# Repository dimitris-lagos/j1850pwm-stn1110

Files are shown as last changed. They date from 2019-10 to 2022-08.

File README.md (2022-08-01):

# j1850pwm-stn1110
OBD 2 interface with atmega328 and STN1110. Output on 16x2 LCD Screen. Implements j1850 pwm protocol.
ATMega328P fuses:
L: 0xFF
H: 0xDD
E: 0xF8
LB: 0xFD

Cad 3D Model Schematic

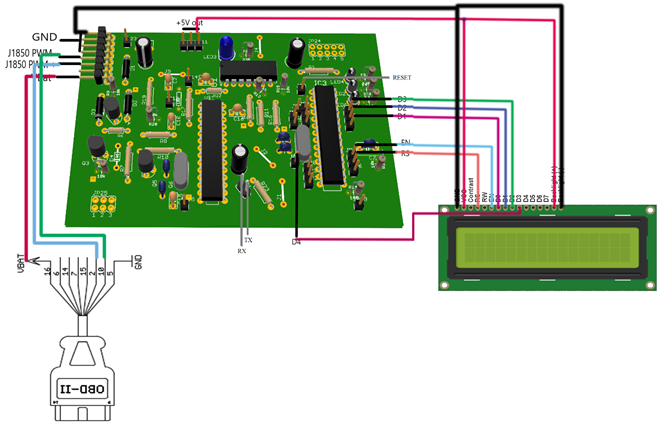
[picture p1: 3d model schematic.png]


Prototype connected to ECU Emulator

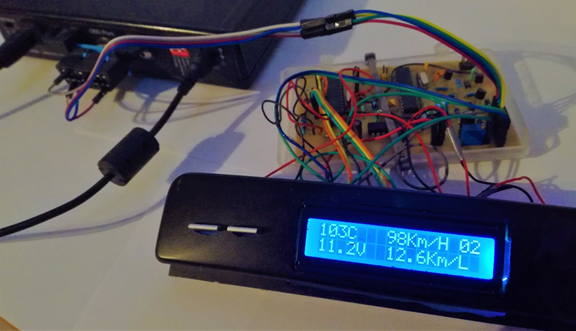
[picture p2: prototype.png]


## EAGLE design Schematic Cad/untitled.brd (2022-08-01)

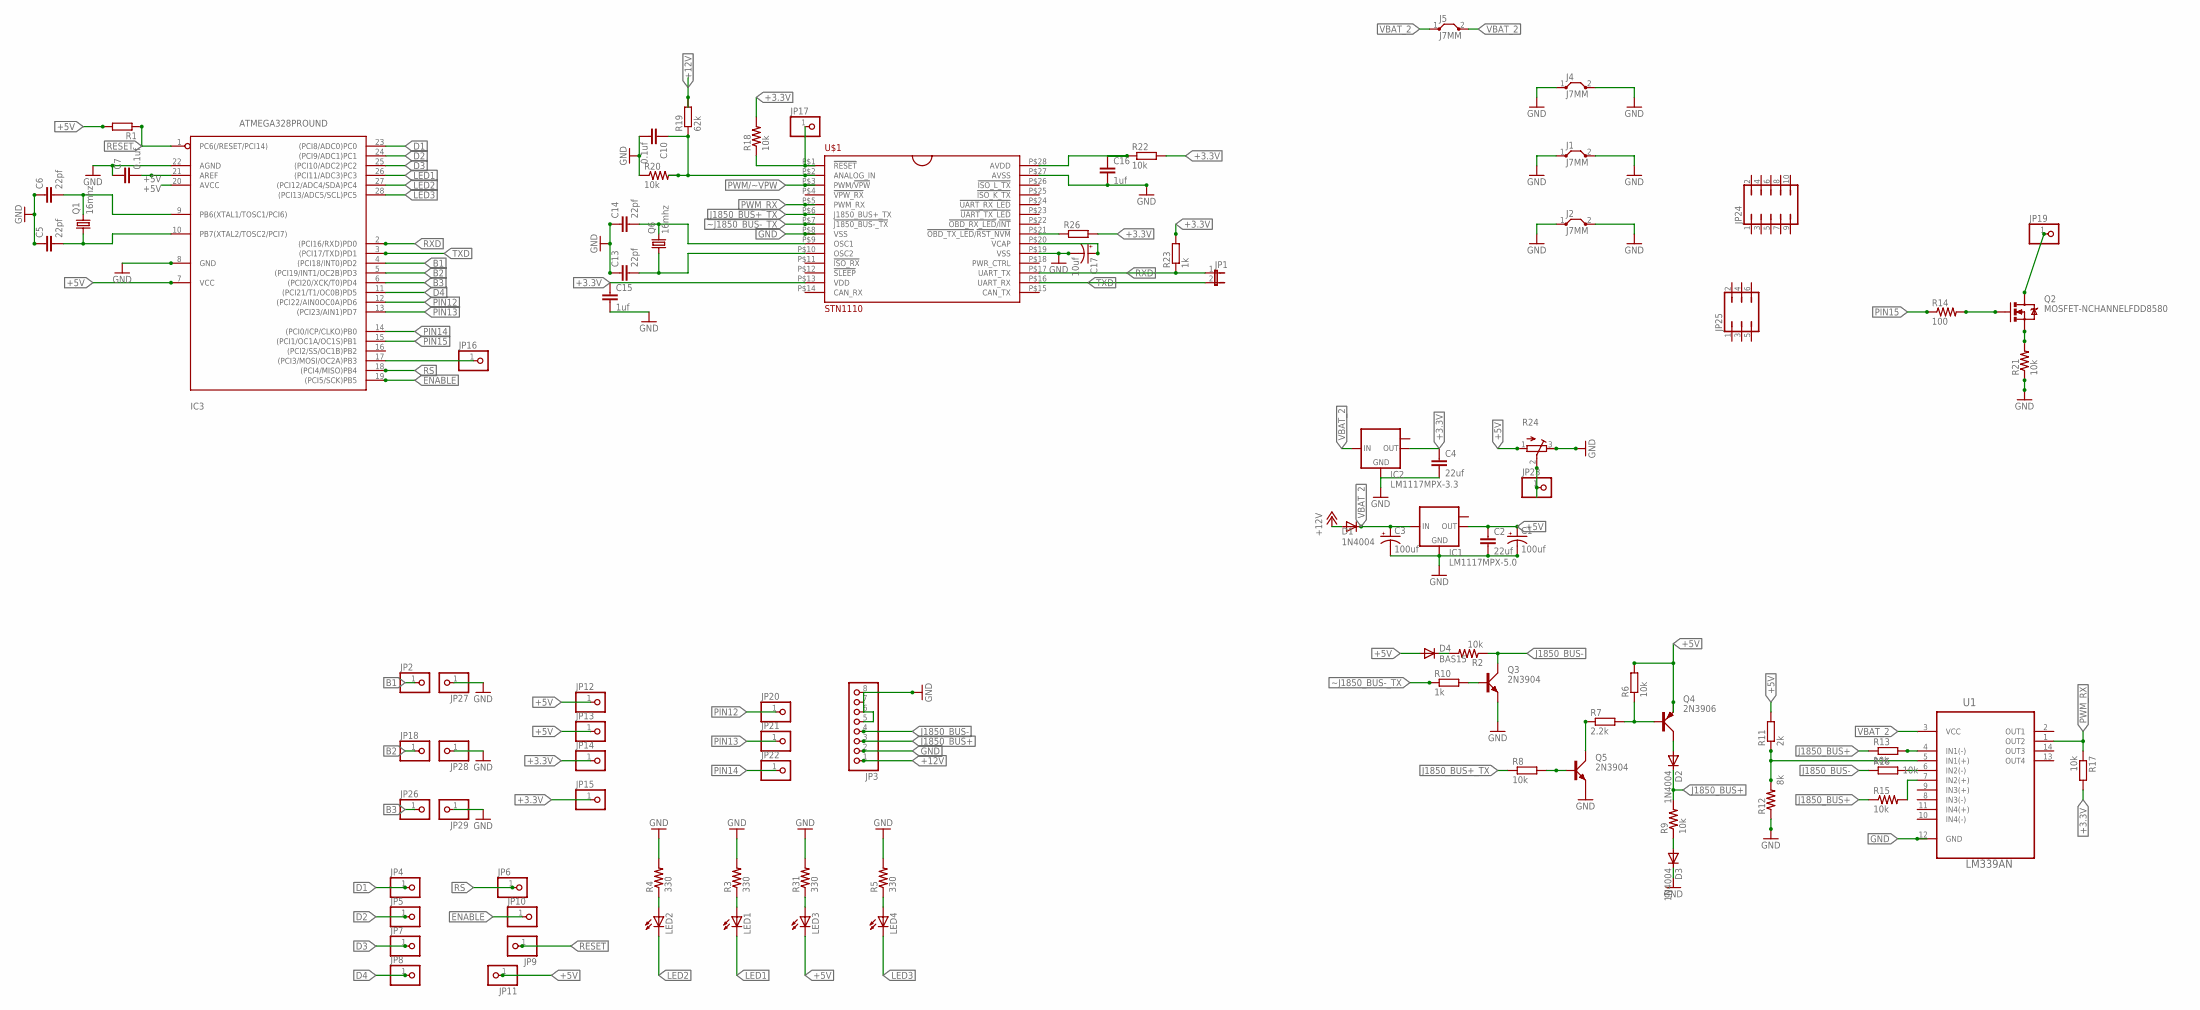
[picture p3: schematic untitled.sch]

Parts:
C1, C3: 100uf; CPOL-RADIAL-10UF-25V-KIT
C2, C4: 22uf; C025-025X050
C5, C6, C13, C14: 22pf; CAP-PTH-SMALL
C7: 0.1uf; C5B4.5
C10: 0.1uf; C025-025X050
C15, C16: 1uf; C025-025X050
C17: 10uf; CPOL-RADIAL-10UF-25V
D1, D2, D3: 1N4004; DO41-10
D4: BAS15; DO34-7
IC1: LM1117MPX-5.0; SOT223
IC2: LM1117MPX-3.3; SOT223
IC3: ATMEGA328PROUND; DIL28-3-ROUND
J1, J2, J4, J5: J7MM; 07
JP1: JP1E; JP1
JP2, JP4, JP5, JP6, JP7, JP8, JP9, JP10, JP11, JP12, JP13, JP14, JP15, JP16, JP17, JP18, JP19, JP20, JP21, JP22, JP23, JP26, JP27, JP28, JP29: PINHD-1X1; 1X01
JP3: PINHD-1X8; 1X08
JP24: JP5Q
JP25: JP3Q
LED1, LED2, LED4: LED3MM
LED3: LED5MM
Q1, Q6: 16mhz; HC49/S
Q2: MOSFET-NCHANNELFDD8580; DPAK
Q3, Q5: 2N3904; TO92D
Q4: 2N3906; TO92D
R1: R-EU_0207/12; 0207/12
R2, R9, R15, R20, R21: 10k; AXIAL-0.1EZ
R3, R4, R5, R31: 330; AXIAL-0.1EZ
R6, R22: 10k; 0204/7
R7: 2.2k; 0207/12
R8, R13, R16: 10k; 0207/10
R10: 1k; 0207/12
R11: 2k; 0207/10
R12: 8k; AXIAL-0.1EZ
R14: 100; AXIAL-0.1EZ
R17: 10k; 0207/12
R18: 10k; AXIAL-0.3EZ
R19: 62k; 0207/12
R23: 1k; 0207/10
R24: R-TRIMM74W; RTRIM74W
R26: R-EU_M3516; M3516
U1: LM339AN; DIP254P762X508-14
U$1: STN1110; SPDIP28

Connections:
+3.3V: C4.1, C15.1, IC2.2 (OUT), JP14.1, JP15.1, R17.2, R18.P$2 (2), R22.2, R23.2, R26.2, U$1.P$13 (VDD)
+5V: C1.1 (+), C2.1, C7.2, D4.A, IC1.2 (OUT), IC3.7 (VCC), IC3.20 (AVCC), IC3.21 (AREF), JP11.1, JP12.1, JP13.1, LED3.K (C), Q4.E, R1.2, R6.2, R11.2, R24.1 (E)
+12V: D1.A, JP3.1, R19.2
AAA: C10.1, R19.1, R20.P$2 (2), U$1.P$2 (ANALOG_IN)
B1: IC3.4 ((PCI18/INT0)PD2), JP2.1
B2: IC3.5 ((PCI19/INT1/OC2B)PD3), JP18.1
B3: IC3.6 ((PCI20/XCK/T0)PD4), JP26.1
D1: IC3.23 ((PCI8/ADC0)PC0), JP4.1
D2: IC3.24 ((PCI9/ADC1)PC1), JP5.1
D3: IC3.25 ((PCI10/ADC2)PC2), JP7.1
D4: IC3.11 ((PCI21/T1/OC0B)PD5), JP8.1
ENABLE: IC3.19 ((PCI5/SCK)PB5), JP10.1
GND: C1.2 (-), C2.2, C3.2 (-), C4.2, C5.1, C6.1, C7.1, C10.2, C13.1, C14.1, C15.2, C16.2, C17.2 (-), D3.C, IC1.1 (GND), IC2.1 (GND), IC3.8 (GND), IC3.22 (AGND), J1.1, J1.2, J2.1, J2.2, J4.1, J4.2, JP3.2, JP3.5, JP3.6, JP3.7, JP3.8, JP27.1, JP28.1, JP29.1, Q3.E, Q5.E, R3.P$2 (2), R4.P$2 (2), R5.P$2 (2), R12.P$1 (1), R20.P$1 (1), R21.P$1 (1), R24.3 (A), R31.P$2 (2), U1.12 (GND), U$1.P$8 (VSS), U$1.P$19 (VSS), U$1.P$27 (AVSS)
J1850_BUS+: D2.C, JP3.3, R9.P$2 (2), R13.1, R15.P$1 (1)
J1850_BUS+_TX: R8.1, U$1.P$6 (J1850_BUS+_TX)
J1850_BUS-: JP3.4, Q3.C, R2.P$1 (1), R16.1
LED1: IC3.26 ((PCI11/ADC3)PC3), LED1.K (C)
LED2: IC3.27 ((PCI12/ADC4/SDA)PC4), LED2.K (C)
LED3: IC3.28 ((PCI13/ADC5/SCL)PC5), LED4.K (C)
unnamed: R26.1, U$1.P$21 (!OBD_TX_LED!/!RST_NVM!)
unnamed: D4.C, R2.P$2 (2)
unnamed: Q4.B, R6.1, R7.2
unnamed: R13.2, U1.4 (IN1(-))
unnamed: Q5.C, R7.1
unnamed: D2.A, Q4.C
unnamed: Q5.B, R8.2
unnamed: Q3.B, R10.2
unnamed: D3.A, R9.P$1 (1)
unnamed: R15.P$2 (2), U1.7 (IN2(+))
unnamed: C16.1, R22.1, U$1.P$28 (AVDD)
unnamed: R16.2, U1.6 (IN2(-))
unnamed: C6.2, IC3.9 (PB6(XTAL1/TOSC1/PCI6)), Q1.2
unnamed: R11.1, R12.P$2 (2), U1.5 (IN1(+))
unnamed: C5.2, IC3.10 (PB7(XTAL2/TOSC2/PCI7)), Q1.1
unnamed: C17.1 (+), U$1.P$20 (VCAP)
unnamed: C14.2, Q6.2, U$1.P$9 (OSC1)
unnamed: C13.2, Q6.1, U$1.P$10 (OSC2)
unnamed: LED3.A, R31.P$1 (1)
unnamed: LED1.A, R3.P$1 (1)
unnamed: JP17.1, R18.P$1 (1), U$1.P$1 (!RESET!)
unnamed: LED2.A, R4.P$1 (1)
unnamed: LED4.A, R5.P$1 (1)
unnamed: IC3.17 ((PCI3/MOSI/OC2A)PB3), JP16.1
unnamed: Q2.1 (G), R14.P$2 (2)
unnamed: Q2.3 (S), R21.P$2 (2)
unnamed: JP23.1, R24.2 (S)
unnamed: JP19.1, Q2.4 (D)
PIN12: IC3.12 ((PCI22/AIN0OC0A)PD6), JP20.1
PIN13: IC3.13 ((PCI23/AIN1)PD7), JP21.1
PIN14: IC3.14 ((PCI0/ICP/CLKO)PB0), JP22.1
PIN15: IC3.15 ((PCI1/OC1A/OC1S)PB1), R14.P$1 (1)
PWM/~VPW: U$1.P$3 (PWM/!VPW!)
PWM_RX: R17.1, U1.1 (OUT2), U$1.P$5 (PWM_RX)
RESET: IC3.1 (PC6(/RESET/PCI14)), JP9.1, R1.1
RS: IC3.18 ((PCI4/MISO)PB4), JP6.1
RXD: IC3.2 ((PCI16/RXD)PD0), JP1.1, R23.1, U$1.P$17 (UART_TX)
TXD: IC3.3 ((PCI17/TXD)PD1), JP1.2, U$1.P$16 (UART_RX)
VBAT_2: C3.1 (+), D1.C, IC1.3 (IN), IC2.3 (IN), J5.1, J5.2, U1.3 (VCC)
~J1850_BUS-_TX: R10.1, U$1.P$7 (!J1850_BUS-_TX!)

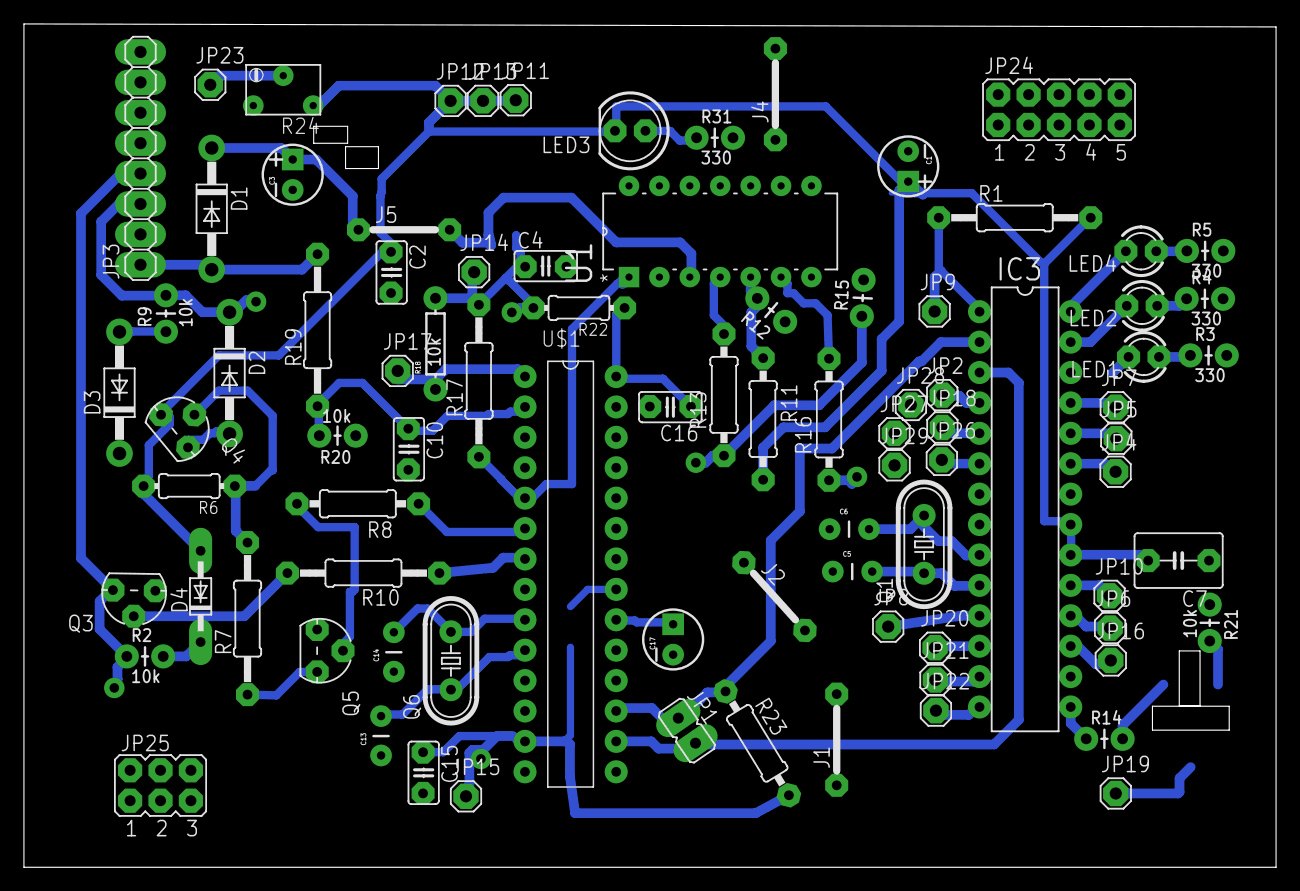
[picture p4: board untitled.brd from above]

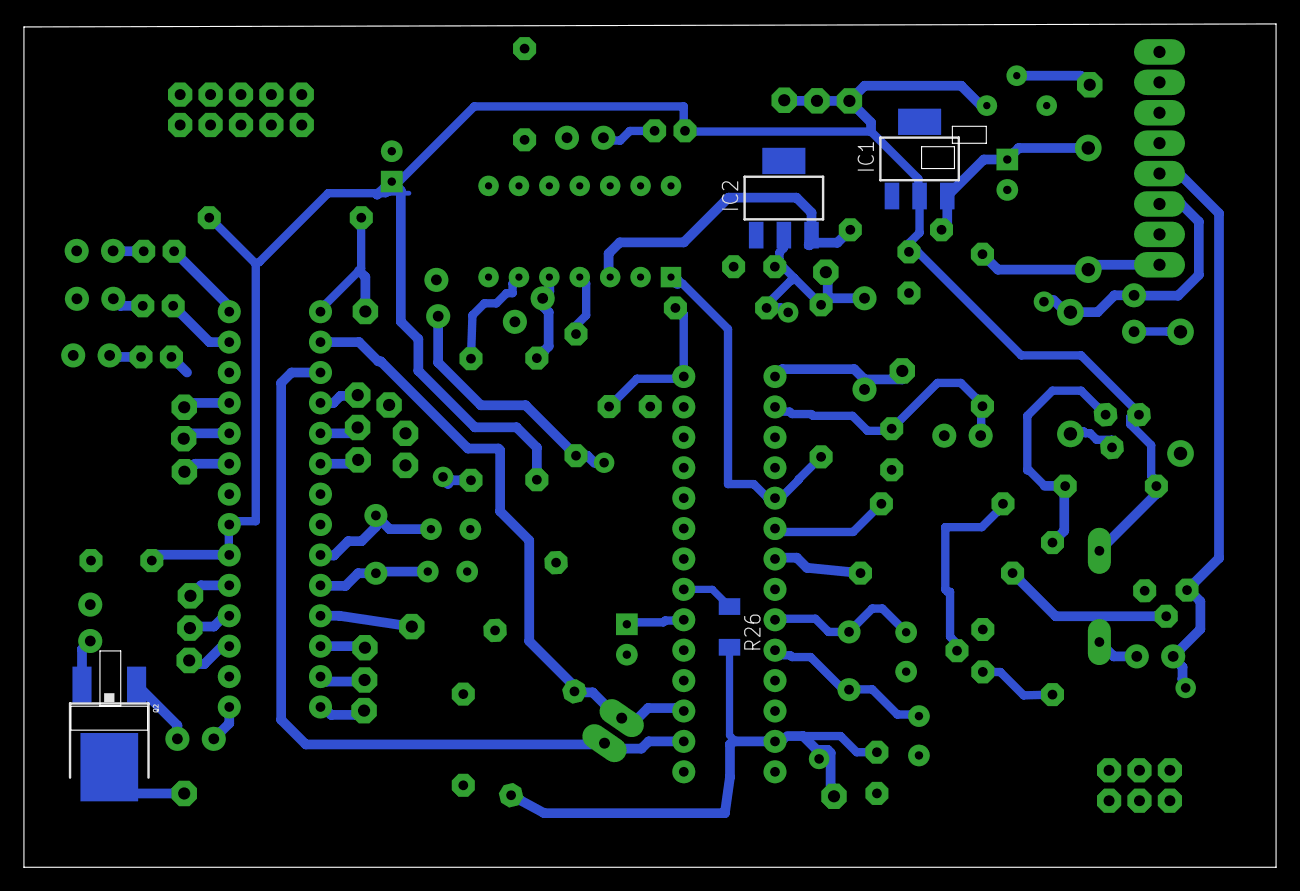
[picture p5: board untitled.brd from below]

Board: 2 copper layers, 104.6 x 70.5 mm, 91 parts (4 on the bottom side), 58 nets.

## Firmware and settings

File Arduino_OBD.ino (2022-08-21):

#include <SoftwareSerial.h> //Χρήση της βιβλιοθήκης που δίνει την δυνατότητα για σειριακή σύνδεση με υλοποίση επιπέδου λογισμικού
#include <avr/wdt.h>        //Χρήση της βιβλιοθήκης υπεύθυνης για την λειτουργία του watchdog timer και συναρτήσεων καθυστέρησης
#include <avr/pgmspace.h>   //Χρήση της EEPROM του ATmega328 για την αποθήκευση των String, ώστε να εξοικονομηθεί χώρος runtime στην sram
#include <LiquidCrystal.h>  // Βιβλιοθήκη που διαχειρίζεται την διασύνδεση με την οθόνη LCD
#include "global.h"
#include "OBD_Interface.h"
#include "LCD_Interface.h"
#include "Debouncy.h"

#define RED_LED 19
#define VENTILATOR_PIN 9
#define BUTTON_1_PIN 2
#define BUTTON_2_PIN 3

/* Η διασύνδεση:
Button Digital Pin 16
LED    Digital Pin 19
Mosfet Digital Pin 9
*/
/* Τμήμα δήλωσης global μεταβλητών */

Debouncy Debouncy_Buttons;
int counter = 0;
float previous_cycle_sterm = 0.00;
float total_cons = 0.00000;// Total consuumption of the vehicle for the current session
float temp_cons = 0.00000;
float real_time_cons = 0.00000;
int menu = 0;
boolean dtc = false;

int threshold = 95;
int temp_thresh = 95;
int analogPin = A3; // potentiometer wiper (middle terminal) connected to analog pin 3
                    // outside leads to ground and +5V

/* Αρχικοποίηση βιβλιοθήκης που διαχειρίζεται την επικοινωνία με την οθόνη,
 με τους ακροδέκτες του Arduino που συνδέονται στην οθόνη  */
LiquidCrystal lcd(12, 13, 5, 14, 15, 16); // LiquidCrystal(rs, enable, d4, d5, d6, d7)

/* Set timer1 interrupt at 1Hz */
void setup_1hz_timer_interrupt(){
  TCCR1A = 0;                                                  // set entire TCCR1A register to 0
  TCCR1B = 0;                                                  // same for TCCR1B
  TCNT1 = 0;                                                   // initialize counter value to 0
  // set compare match register for 1hz increments
  OCR1A = 15624; // = (16*10^6) / (1*1024) - 1 (must be <65536)
  // turn on CTC mode
  TCCR1B |= (1 << WGM12);
  // Set CS12 and CS10 bits for 1024 prescaler
  TCCR1B |= (1 << CS12) | (1 << CS10);
  // enable timer compare interrupt
  TIMSK1 |= (1 << OCIE1A);
}


/* Setup the i/o pin that drives the mosfet that turns on and off the fridge ventilator */
void setup_ventilator_mosfet_driver_pin(){
  pinMode(VENTILATOR_PIN, OUTPUT);   //Ορισμός ακροδέκτη 9 ως έξοδο ventilator mosfet
  digitalWrite(VENTILATOR_PIN, LOW); // ventilator off
}

/* Η συνάρτηση που αρχικοποιεί τις βασικές ρυθμίσεις για την διασύνδεση
 των περιφερειακών και των λειτουργιών του προγράμματος */
void setup()
{
  Debouncy_Buttons.setupDebouncedButton(BUTTON_1_PIN, button1);
  Debouncy_Buttons.setupDebouncedButton(BUTTON_2_PIN, button2);
  setup_ventilator_mosfet_driver_pin();
  init_STN_Serial_Interface();
  // set up the LCD's number of columns and rows:
  lcd.begin(LCD_NUMBER_OF_COLUMNS, LCD_NUMBER_OF_ROWS); //Ορισμός γραμμών και στηλών της οθόνης(2x16)
  pinMode(RED_LED, OUTPUT);                                  //Ορισμός ακροδέκτη 19 ως έξοδο(LED 1)
  setup_1hz_timer_interrupt();

  lcd.clear();
  digitalWrite(RED_LED, HIGH); // LED on
  delay(1000);            // Καθυστέρηση 1sec
  lcd.setCursor(0, 0);    /* μετακίνηση του κέρσορα στην πρώτη γραμμή και πρώτη στήλη της οθόνης */
  lcd.write(WELLCOME_TEXT); /* Γράψε στην οθόνη το κείμενο εισαγωγής*/
  digitalWrite(RED_LED, LOW);  // LED off
  delay(1000);
  wait_for_STN_ready();
  setup_STN_communication_properties();
  menu = 0;
  send_init_page_to_lcd();


  sei();       //ενεργοποίηση της εξυπηρέτησης των διακοπών
}

void send_init_page_to_lcd(){
  lcd.setCursor(0, 1);
  float fuel_lvl = read_fuel_lvl();
  lcd.print(fuel_lvl, 1);
  lcd.print(" %F  ");
  lcd.print(calculate_fuel_in_liters(fuel_lvl), 1);
  lcd.print(" L");
  delay(5000); //περίμενε 5"
}

ISR(TIMER1_COMPA_vect)
{
  if (counter == 0)
  {
    counter = 1;
  }
  total_cons += (temp_cons / (float)counter);
  temp_cons = 0;
  counter = 0;
}



void loop()
{
  read_temp_threshold();
  int coolant_temp = read_coolant_temperature();//Διάβασε την θερμοκρασία του οχήματος
  float fuel_consumption = calculate_fuel_consumption();
  float milage = calculate_milage(fuel_consumption);
  if(dtc){
    dtc = false;
    read_dtc();
  }
  switch (menu)
  {
  case 0: //Επίλεξε σελίδα πληροφοριών 1
    char battery_voltage[6];
    read_battery_voltage(battery_voltage);
    send_page1_to_lcd(coolant_temp, battery_voltage, fuel_consumption, milage);    //Στείλε τα δεδομένα στην οθόνη
    break;
  case 1: //Επίλεξε σελίδα πληροφοριών 2
    send_page2_to_lcd(read_fuel_lvl(), read_fstat());        //Στείλε τα δεδομένα στην οθόνη
    break;
  case 2://Επίλεξε σελίδα πληροφοριών 3
    FordSpecificTemperatures fordTemps;
    read_Ford_specific_temperatures(&fordTemps); //Διάβασε την θερμοκρασία των κυλίνδρων
    send_page3_to_lcd(coolant_temp, fordTemps.uknown_temperature, fordTemps.cylinder_temperature); //Στείλε τα δεδομένα στην οθόνη
    break;
  case 3: //Επίλεξε σελίδα πληροφοριών 3
    send_page4_to_lcd(read_maf(), read_oxvolts(), previous_cycle_sterm, read_fterm());        //Στείλε τα δεδομένα στην οθόνη
    break;
  // case 4:
  //  send_page5_to_lcd(medium_milage);
  //  break;
  }
  delay(10);
}

 /* Συνάρτηση που διαχειρίζεται το πάτημα του κουμπιού 1 */
void button1(unsigned int holdTime){
    ++menu;
    if (menu == 4){
      menu = 0;
    }
    delay(20);
}

/* Συνάρτηση που διαχειρίζεται το πάτημα του κουμπιού 2 */
void button2(unsigned int holdTime) {
    delay(50);
    dtc = true;
} 


void read_temp_threshold()
{
  int val = analogRead(analogPin);
  if (val >= 0 && val < 85)
    threshold = 90;
  else if (val >= 86 && val < 170)
    threshold = 101;
  else if (val >= 171 && val < 255)
    threshold = 102;
  else if (val >= 256 && val < 340)
    threshold = 103;
  else if (val >= 341 && val < 425)
    threshold = 104;
  else if (val >= 426 && val < 510)
    threshold = 105;
  else if (val >= 511 && val < 595)
    threshold = 106;
  else if (val >= 596 && val < 680)
    threshold = 107;
  else if (val >= 681 && val < 765)
    threshold = 108;
  else if (val >= 766 && val < 850)
    threshold = 109;
  else if (val >= 851 && val < 935)
    threshold = 110;
  else if (val >= 936)
    threshold = 120;
  if (threshold != temp_thresh)
  {
    temp_thresh = threshold;
    inform_temperature_threshold_changed();
  }
}

void inform_temperature_threshold_changed()
{
  lcd.clear();
  lcd.setCursor(1, 0);
  lcd.print(threshold, DEC);
  lcd.print("C Threshold");
  delay(200);
}


void check_coolant_temperature_threshold(int temperature)
{
  if (temperature > threshold && temperature < 250)
  {
    digitalWrite(RED_LED, HIGH);
    digitalWrite(VENTILATOR_PIN, HIGH);
  } /* Αν η θερμοκρασία του ψυκτικού είναι μεγαλύτερη του threshold, άναψε το LED 2 και άνοιξε το ventilator*/
  else
  {
    digitalWrite(RED_LED, LOW);
    digitalWrite(VENTILATOR_PIN, LOW);
  }
}





float calculate_fuel_consumption()
{
  float maf = read_maf();
  int spd = read_vehicle_speed();
  cli();
  float consumption = 0.00;
  real_time_cons = ((maf / 10437.00000) * (1 + (previous_cycle_sterm / 100)) * DEVIATION_FACTOR);// After testing my car consumed 17% more fuel.
  if (spd > 0)
  {
    consumption = (spd / 3600.00) / real_time_cons; //(spd/3600)*((14,7*710)/maf);
    //milage = 100.00 / cons;
  }
  temp_cons += real_time_cons;
  ++counter;
  sei();
  previous_cycle_sterm = read_sterm(); //Διαβάζουμε έδω το short term fuel trim για να εφαρμοστεί στον επόμενο κύκλο
  return consumption;
}



// void send_page5_to_lcd(float milage){
//   lcd.clear();
//     if (milage >= 10)
//   {
//     lcd.setCursor(6, 0);
//   }
//   else
//   {
//     lcd.setCursor(7, 0);
//   }
//   lcd.print(milage, 1);
//   lcd.print(" L/100");
// }

/* Συνάρτηση η οποία εμφανίζει τα δεδομένα της πρώτης σελίδας στην οθόνη */
/*Αναλόγως πόσα ψηφία έχει η τιμή, βάζει τον κέρσορα στη σωστή θέση της
οθόνης ώστε οι πληροφορίες να είναι ευανάγνωστες. Επίσης εκτυπώνει τις μονάδες
των τιμών στα σωστά σημεία*/
void send_page1_to_lcd(int coolant_temperature, char* bat, float cons, float milage)
{
  int i = 0;
  lcd.clear();
  if (coolant_temperature <= -10)
  {
  }
  else if (coolant_temperature < 0 and coolant_temperature > -10)
  {
    lcd.setCursor(1, 0);
    i = 1;
  }
  else if (coolant_temperature < 10)
  {
    lcd.setCursor(2, 0);
    i = 2;
  }
  else if (coolant_temperature < 100)
  {
    lcd.setCursor(1, 0);
    i = 1;
  }
  lcd.print(coolant_temperature, DEC);
  lcd.print("C  ");
  if (milage >= 10)
  {
    lcd.setCursor(6, 0);
  }
  else
  {
    lcd.setCursor(7, 0);
  }
  lcd.print(milage, 1);
  lcd.print(" L/100");
  lcd.setCursor(0, 1);
  lcd.write(bat);
  lcd.print("  ");
  if (cons < 10)
  {
    lcd.print(" ");
  }
  lcd.print(cons, 1);
  lcd.print(" Km/L");
}

/* Συνάρτηση η οποία εμφανίζει τα δεδομένα της δεύτερης σελίδας στην οθόνη */
void send_page2_to_lcd(float fuel_lvl, int fstat)
{
  int i = 0;
  lcd.clear();
  if (total_cons < 10)
  {
    lcd.setCursor(2, 0);
  }
  else if (total_cons < 100)
  {
    lcd.setCursor(1, 0);
  }
  lcd.print(total_cons, 3);
  lcd.print("L Cons ");
  lcd.setCursor(0, 1);
  if (fuel_lvl < 10)
  {
    lcd.setCursor(1, 1);
  }
  lcd.print(fuel_lvl, 1);
  lcd.print(" % ");
  lcd.print(calculate_fuel_in_liters(fuel_lvl), 1);
  lcd.print(" L");
  lcd.setCursor(14, 1);
  lcd.print(fstat);
}

/* Συνάρτηση η οποία εμφανίζει τα δεδομένα της τρίτης σελίδας στην οθόνη */
void send_page3_to_lcd(int coolant_temperature, int unknown_temperature, int cylinder_temperature)
{
  lcd.clear();
  lcd.print("C1 ");
  lcd.print(coolant_temperature, DEC);
  lcd.print("C ");
  lcd.print("C2 ");
  lcd.print(unknown_temperature, DEC);
  lcd.print("C");
  lcd.setCursor(0, 1);
  lcd.print("Cyl ");
  lcd.print(cylinder_temperature, DEC);
  lcd.print("C");
}
void send_page4_to_lcd(float mass_air_flow, float oxygen_volts, float sterm, float fterm)
{
  lcd.clear();
  lcd.print(mass_air_flow, 2);
  lcd.print("G/s ");
  lcd.print(oxygen_volts, 3);
  lcd.print("V");
  lcd.setCursor(0, 1);
  lcd.print(sterm, 2);
  lcd.print("% ");
  lcd.print(fterm, 2);
  lcd.print("%");
}


float calculate_fuel_in_liters(float fuel_tank_percentage){
  return fuel_tank_percentage * 0.55;
}

/* Calculate the milage in fuel liters per 100km, given the kilometers per liter consumption */
float calculate_milage(float fuel_consumption){
  if(fuel_consumption>0.00){
    return 100.00 / fuel_consumption;
  }
  return 0.00;

}

/* Συνάρτηση που διαβάζει και αποκωδηκοποιεί την κατάσταση σφαλμάτων του οχήματος  */
void read_dtc()
{
  int i = 1;
  char tmp[2];

  /* Διαβάζει 4 byte: Α, Β, C και D
  Το πρώτο byte (A) περιέχει δύο στοιχεία.
  Το Bit A7 (MSB του byte A, το πρώτο byte) δείχνει εάν το MIL (λαμπάκι βλάβης του κινητήρα)
  ανάβει ή όχι. Τα bits A6 έως A0 αντιπροσωπεύουν τον αριθμό διαγνωστικών κωδικών βλάβης που
  επισημαίνονται επί του παρόντος στο ECU.
  Το δεύτερο, το τρίτο και το τέταρτο bytes (B, C και D) παρέχουν πληροφορίες σχετικά με τη
  διαθεσιμότητα και την πληρότητα ορισμένων δοκιμών επί του οχήματος*/
  lcd.clear();
  lcd.setCursor(0, 0);
  unsigned int active_dtcs = get_dtc_number();
  if (active_dtcs)
  {
    lcd.print(active_dtcs);
    lcd.print(" DTCs FOUND!");
    delay(3000);   //Πάγωσε την οθόνη για 3" ώστε ο χρήστης να προλάβει να διαβάσει
    read_active_dtc();
    lcd.clear();
    lcd.setCursor(0, 0);
    for (int j = 1; j <= active_dtcs; j++)
    { // byte#0 is only the mode reply-not needed
      if (stn_buffer[i] <= 0x3F)
      {
        lcd.print("P");
        sprintf(tmp, "%02x", stn_buffer[i]);
        lcd.print(tmp);
        sprintf(tmp, "%02x", stn_buffer[i + 1]);
        lcd.print(tmp);
        lcd.print(" ");
      }
      else if (stn_buffer[i] <= 0x7F)
      {
        lcd.print("C");
        lcd.print((stn_buffer[i] >> 4) - 4);
        lcd.print(stn_buffer[i] && 0b00001111);
        sprintf(tmp, "%02x", stn_buffer[i + 1]);
        lcd.print(tmp);
        lcd.print(" ");
      }
      else if (stn_buffer[i] <= 0xBF)
      {
        lcd.print("B");
        lcd.print((stn_buffer[i] >> 4) - 8);
        lcd.print(stn_buffer[i] && 0b00001111);
        sprintf(tmp, "%02x", stn_buffer[i + 1]);
        lcd.print(tmp);
        lcd.print(" ");
      }
      else
      {
        lcd.print("U");
        lcd.print((stn_buffer[i] >> 4) - 12);
        lcd.print(stn_buffer[i] && 0b00001111);
        sprintf(tmp, "%02x", stn_buffer[i + 1]);
        lcd.print(tmp);
        lcd.print(" ");
      }
      i = i + 2;
      if (j == 3)
      {
        lcd.setCursor(0, 1);
      }
    }

    delay(8000); //Πάγωσε την οθόνη για 8" ώστε ο χρήστης να προλάβει να διαβάσει
  }
  else
  {
    lcd.print("NO DTCs FOUND");
    delay(2000);
  }
}

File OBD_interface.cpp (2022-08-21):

#include "OBD_Interface.h"

char inByte;
int stn_buffer[16];
void init_STN_Serial_Interface(){
    Serial.begin(115200); //Εκίνηση της σειριακής επικοινωνίας με το STN1110 Baud 115200
}
/* Συνάρτηση που παίρνει σαν όρισμα ένα δείκτη σε πίνακα χαρακτήρων
 που περιέχει την εντολή(PID) προς αποστολή και αποθηκεύη τα δεδομένα
 που λαμβάνονται ως απάντηση απο το STN1110 σε έναν buffer */
void stn_com(char *str)
{ // str είναι η εντολή που στέλνουμε και bytes ο αριθμός των bytes μαζί με το '>'
  int s = 0;
  int i = 0;
  char value[3];
  Serial.print(str);
  Serial.print("\r"); // send end of transmission char.
  while (Serial.available() < 1){}
  inByte = 'A';
  while (inByte != '>'){ //'>'=0x3E
    if (Serial.available() > 0)
    {
      inByte = Serial.read();
      if ((inByte < 91 and inByte > 64) or (inByte >= 45 and inByte < 58))
      { // strip from spaces/carriage return etc etc
        value[i++] = inByte;
        if (i == 2)
        { //Κάθε 2 ASCII χαρακτήρες είναι ένα 16δικο BYTE
          value[i] = '\0';
          i = 0;
          stn_buffer[s++] = hexToDec(value); //Μετατροπή από ASCII σε INT
        }
      }
    }
  }
}

void wait_for_STN_ready(){
while (Serial.available() < 1){} //Αναμονή μέχρι η σειριακή σύνδεση να είναι διαθέσιμη
  char inByte = 'A';
  while (inByte != '>')
  { //Διάβασε τους χαρακτήρες που λαμβάνονται από την σειριακή σύνδεση
    //χαρακτήρας τερματισμού ">"
    inByte = Serial.read();
  }
}

void setup_STN_communication_properties(){
  stn_com("atsp1"); // set protocol jpwm
  stn_com("ats0");  // spaces off on replies from stn1110
  delay(50);
}

/* Συνάρτηση η οποία παίρνει σαν όρισμα ASCII χαρακτήρες(κάθε χαρακτήρας 1 byte) και επιστρέφει τον αντίστοιχο 10δικό.
Το STN1110 δεν στέλνει 16δικο, στέλνει ASCII, άρα κάθε ΗΕΧ ΒΥΤΕ αποστέλνεται από το STN1110 με 2 χαρακτήρες*/
unsigned int hexToDec(String hexString)
{

  unsigned int decValue = 0;
  int nextInt;

  for (int i = 0; i < hexString.length(); i++)
  {

    nextInt = int(hexString.charAt(i));
    if (nextInt >= 48 && nextInt <= 57)
      nextInt = map(nextInt, 48, 57, 0, 9);
    if (nextInt >= 65 && nextInt <= 70)
      nextInt = map(nextInt, 65, 70, 10, 15);
    if (nextInt >= 97 && nextInt <= 102)
      nextInt = map(nextInt, 97, 102, 10, 15);
    nextInt = constrain(nextInt, 0, 15);

    decValue = (decValue * 16) + nextInt;
  }

  return decValue;
}

/* Συνάρτηση που διαβάζει και αποκωδηκοποιεί την τιμή της τρέχουσας θερμοκρασίας του ψυκτικού υγρού του οχήματος */
int read_coolant_temperature()
{
  stn_com("0105");           // AT command: Mode:01 PID: 05
  return (stn_buffer[2] - 40); //Α-40
}

/* Συνάρτηση που διαβάζει και αποκωδηκοποιεί την τιμή της τρέχουσας ταχύτητας του οχήματος */
int read_vehicle_speed()
{
  stn_com("010D");     // AT command: Mode:01 PID: 0D
  return stn_buffer[2]; //Μετατροπή της τιμής από δεκαεξαδικό σε δεκαδικό
  //Α
}


/* Συνάρτηση που διαβάζει και αποκωδηκοποιεί την τιμή του Short Term Fuel Trim της μηχανής  */
float read_sterm()
{
  stn_com("0106"); // AT command: Mode:01 PID: 06
  //Μετατροπή της τιμής από δεκαεξαδικό σε δεκαδικό
  return ((float)stn_buffer[2] / 1.28) - 100.00; //(A/1.28)-100
}

/* Συνάρτηση που διαβάζει και αποκωδηκοποιεί την τιμή του Long Term Fuel Trim της μηχανής */
float read_fterm()
{
  stn_com("0107");                                // AT command: Mode:01 PID: 06
  return ((float)stn_buffer[2] / 1.28) - 100.00; //(A/1.28)-100
}

/* Συνάρτηση που διαβάζει και αποκωδηκοποιεί την τιμή του αισθητήρα οξυγόνου του οχήματος  */
float read_oxvolts()
{
  stn_com("0114");                                // AT command: Mode:01 PID: 14
  //sterm2 = ((float)stn_buffer[3] / 1.28) - 100.0; // (B/1.28)-100
  return ((float)stn_buffer[2] / 200.000);      // A/200
}

/* Συνάρτηση που διαβάζει και αποκωδηκοποιεί την κατάσταση κυκλώματος της μηχανής του οχήματος  */
int read_fstat()
{
  stn_com("0103"); // AT command: Mode:01 PID: 03
  return stn_buffer[2];
}

float read_fuel_lvl()
{
  stn_com("atsh e410f1");                                            //Αλλαγή του header σε Ford Manufacturer Extended PID mode(22=physical addressing mode)
  stn_com("2216C1");                                                 //Διάβασε το ποσοστό πλήρωσης % του καυσίμου(MODE=22 και PID=16C1)
  float fuel_lvl = (float)((256 * stn_buffer[3]) + stn_buffer[4]) * 0.003; //Μετατροπή της τιμής από δεκαεξαδικό σε δεκαδικό
  //fuel = fuel_lvl * 0.55;
  stn_com("atsh 616af1"); //Επανέφερε τον header σε Standard PID Mode
  return fuel_lvl;
}

/* Συνάρτηση που διαβάζει και αποκωδηκοποιεί την τιμή της τρέχουσας μάζας εισαγωγής αέρα στην μηχανή του οχήματος */
/* Επίσης διενεργεί υπολογισμό κατανάλωσης καυσίμου σε Χιλιόμετρα ανά Λίτρο */
float read_maf()
{
  stn_com("0110"); // AT command: Mode:01 PID: 10
  unsigned int maf1 = (256 * stn_buffer[2]) + stn_buffer[3];
  /* 256*(A+B)/100 */
  /* Τμήμα κώδικα που υπολογίζει την κατανάλωση καυσίμου */
  float maf2 = ((float)maf1) / 100.00;
  return maf2;
}


/* Συνάρτηση που διαβάζει την τιμή της τάσης της μπαταρίας του οχήματος  */
char* read_battery_voltage(char *bat)
{
  // H τιμή της τάσης της μπαταρίας είναι σε ASCII, οπότε απλά αντιγράφουμε τους χαρακτήρες
  int s = 0;
  Serial.print("atrv\r"); // AT command: ATRV
  while (Serial.available() < 1){}
  char inByte = 'A';
  while (inByte != '>')
  { //'>'=0x3E
    if (Serial.available() > 0)
    {
      inByte = Serial.read();
      if ((inByte < 91 and inByte > 64) or (inByte >= 45 and inByte < 58))
      { // strip from spaces/carriage return etc etc
        stn_buffer[s++] = inByte;
      }
    }
  }
  bat[0] = stn_buffer[0];
  bat[1] = stn_buffer[1];
  bat[2] = stn_buffer[2];
  bat[3] = stn_buffer[3];
  bat[4] = stn_buffer[4];
  bat[5] = '\0';

  return bat;
}

void read_Ford_specific_temperatures(FordSpecificTemperatures *fordTemps)
{
  stn_com("atsh e410f1"); //Αλλαγή του header σε Ford Manufacturer Extended PID mode(22=physical addressing mode)
  stn_com("221624");      // Δίαβασε την θερμοκρασία των κυλίνδρων(MODE=22 και PID=1624)

  int temp2 = stn_buffer[3];
  int temp3 = stn_buffer[4];
  if (temp2 == 0)
  {
    (temp2 = temp3 * 2);
  }
  else if (temp2 <= 127)
  {
    temp2 = (temp2 * 512) + (temp3 * 2);
  }
  else
  {
    temp2 = (temp2 - 254) * 512 + temp3 * 2;
  }
  temp2 = (float)(temp2 - 32) * (float)(0.56);

  stn_com("221139"); //Διάβασε την θερμοκρασία του ψυκτικού(αισθητήρας 2)(MODE=22 και PID=1139)
  temp3 = stn_buffer[3];

  stn_com("atsh 616af1"); //Επανέφερε τον header σε Standard PID Mode

  fordTemps->cylinder_temperature = temp2;
  fordTemps->uknown_temperature = temp3;
}

bool check_mil(){
  stn_com("0101");
  if (stn_buffer[2] & 0b10000000){
    return true;
  }
  return false;
}

int get_dtc_number(){
  stn_com("0101");
  if (stn_buffer[2] & 0b10000000){ // if we got MIL ON and active DTCs
    return stn_buffer[2] - 0x80; // byte-128 to find how many active dtcs exist cause of mil bit
  }
  else{
    return stn_buffer[2] & 0b01111111;
  }
}
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

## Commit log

2020-05-29 Add files via upload
    -Code Update-
    Fix DTC's not reading correctly when MIL off
    Add Ventilator Relay control from setting a threshold temperature.
2022-07-31 code refactor
    Code refactor so that the project can be built using Visual Studio Code and Arduino CLI
2022-08-01 Added Project Cad Files
    [DRILEGEND.CFG, untitled.brd, untitled.sch]
2022-08-19 Button Debounce Fix
2026-09-08 Rework fuel consumption calculation and STN1110 communication
    Fuel consumption:
    - Integrate fuel with the real dt between MAF samples (trapezoidal) instead
    of the 1 Hz Timer1 ISR, so every interval is counted exactly once
    - Accumulate the session total in integer microliters
    - Use AFR 14.4 (E5) and density 745 g/L, apply PID 03 fuel system status
    factors for open loop, and apply STFT+LTFT (APPLY_FUEL_TRIMS)
    - Remove the empirical DEVIATION_FACTOR
    STN1110 layer:
    - Validate every response (mode, PID, length, clean hex), zero the buffer
    before each request, bound the buffer, add a 1 s receive timeout
    - Send PID requests with the expected-response-count digit, explicit ATE0
    - Active "ati"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

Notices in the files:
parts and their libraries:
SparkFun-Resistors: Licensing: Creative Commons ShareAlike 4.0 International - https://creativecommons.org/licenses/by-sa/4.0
